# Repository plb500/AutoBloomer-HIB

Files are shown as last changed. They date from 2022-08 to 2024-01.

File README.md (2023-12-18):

# AutoBloomer Hardware Interface Board

Code and PCB design for the Hardware Interface Board, the board used by the Raspberry Pi to process sensor data and trigger relays.

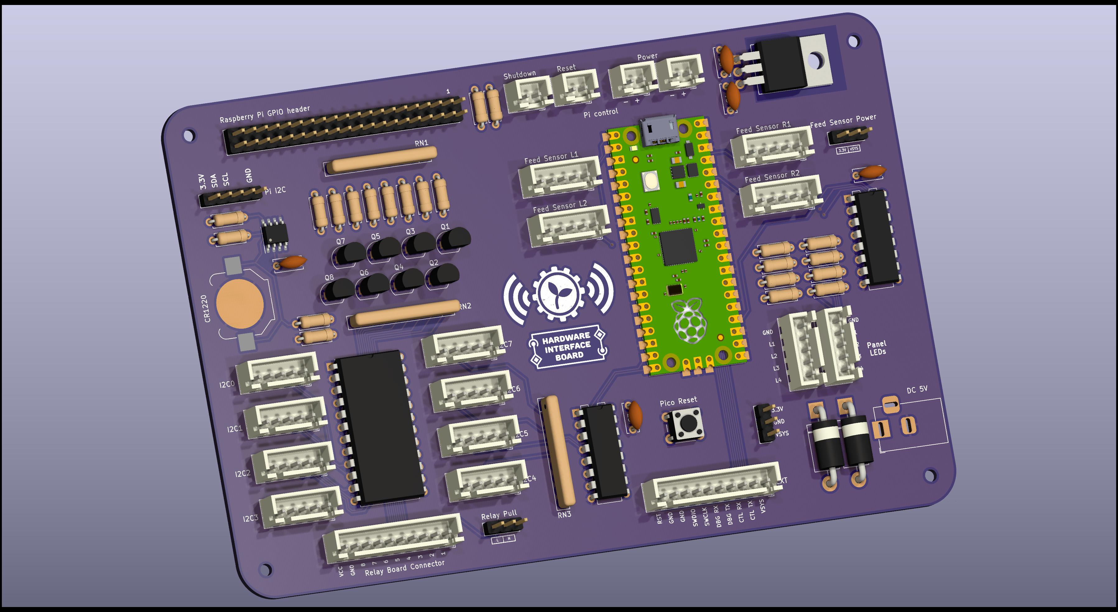
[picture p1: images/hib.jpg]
Hardware Interface Board graphic


## Features
- Raspberry Pi RTC module
- I2C expander providing up to 8 I2C device slots, along with plug detection pins for the Raspberry Pico
- Sensor multiplexing to Raspberry Pi via Raspberry Pico
- Feed level sensors
- Soil moisture sensing
- SCD30 sensing
- Ports for 8 panel/indicator LEDs
- Raspberry Pi power output ports
- Headers for external Pi shutdown/reset and Pico reset buttons
- Control circuitry and interface for properly driving common 5v relay boards (Sainsmart etc)
- Serial Wire Debug (SWD) pins exposed for debugging/programming Raspberry Pico

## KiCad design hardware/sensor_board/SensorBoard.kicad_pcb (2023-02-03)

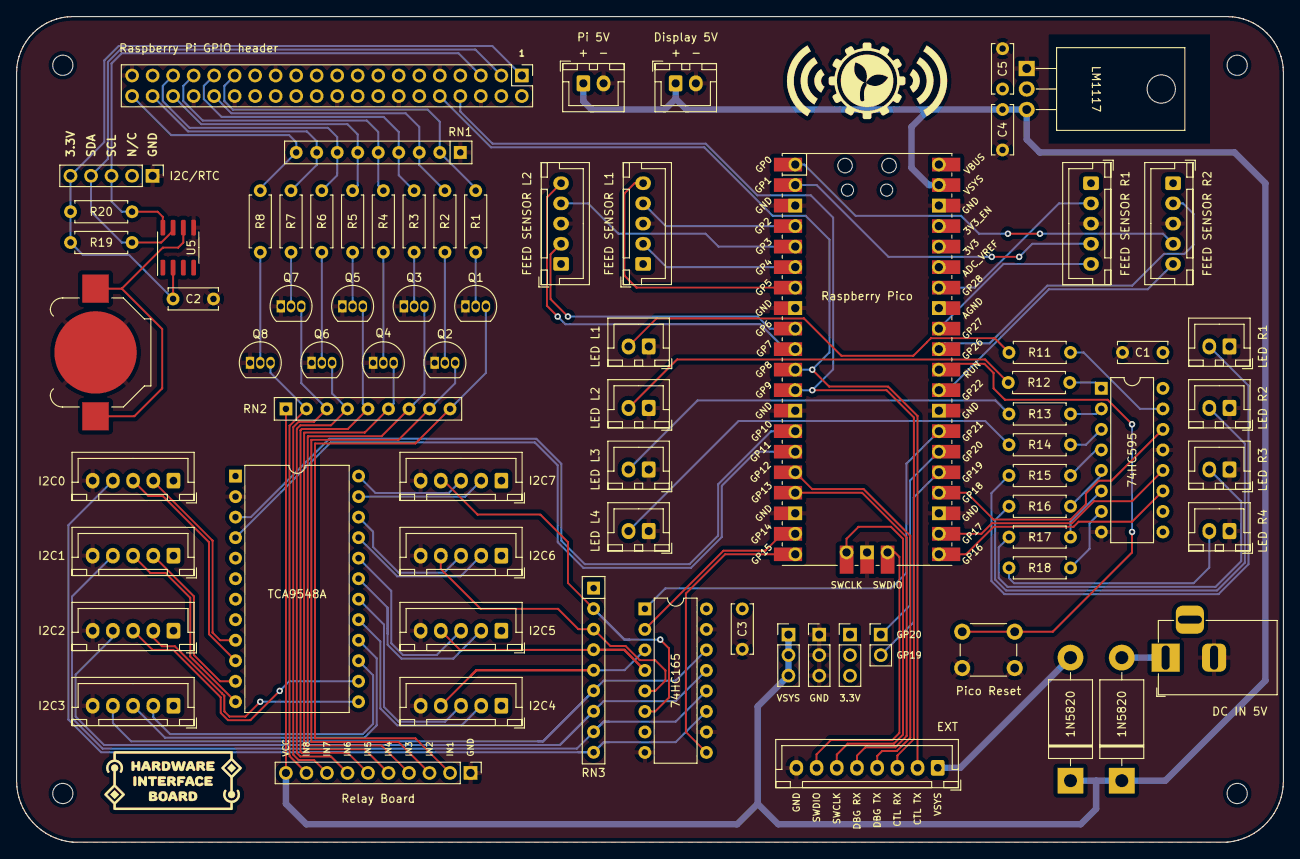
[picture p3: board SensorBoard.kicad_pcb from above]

Board: 2 copper layers, 156.9 x 102.2 mm, 79 parts (0 on the bottom side), 102 nets.

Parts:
BT1: CR1220; BatteryHolder_Keystone_3000_1x12mm
C1, C2, C3: 0.1uf; C_Disc_D6.0mm_W2.5mm_P5.00mm
C4, C5: 10uf; C_Disc_D6.0mm_W2.5mm_P5.00mm
D1, D2: 1N5820; D_DO-201AD_P15.24mm_Horizontal
H1, H2, H3, H4: MountingHole_2.5mm
J1: Relay Board; PinHeader_1x10_P2.54mm_Vertical
J2: Pi 5V; JST_XH_B2B-XH-A_1x02_P2.50mm_Vertical
J3: Display 5V; JST_XH_B2B-XH-A_1x02_P2.50mm_Vertical
J4: DC IN 5V; BarrelJack_Horizontal
J5: VSYS BUS; PinHeader_1x03_P2.54mm_Vertical
J6: FEED SENSOR L1; JST_XH_B5B-XH-A_1x05_P2.50mm_Vertical
J7: 3V3 BUS; PinHeader_1x03_P2.54mm_Vertical
J8: FEED SENSOR R1; JST_XH_B5B-XH-A_1x05_P2.50mm_Vertical
J9: FEED SENSOR L2; JST_XH_B5B-XH-A_1x05_P2.50mm_Vertical
J10: GND BUS; PinHeader_1x03_P2.54mm_Vertical
J11: FEED SENSOR R2; JST_XH_B5B-XH-A_1x05_P2.50mm_Vertical
J13: SPARE GPIO; PinHeader_1x02_P2.54mm_Vertical
J15: LED L1; JST_XH_B2B-XH-A_1x02_P2.50mm_Vertical
J16: LED L2; JST_XH_B2B-XH-A_1x02_P2.50mm_Vertical
J17: LED L3; JST_XH_B2B-XH-A_1x02_P2.50mm_Vertical
J18: LED L4; JST_XH_B2B-XH-A_1x02_P2.50mm_Vertical
J19: LED R1; JST_XH_B2B-XH-A_1x02_P2.50mm_Vertical
J20: EXT; JST_XH_B8B-XH-A_1x08_P2.50mm_Vertical
J21: LED R2; JST_XH_B2B-XH-A_1x02_P2.50mm_Vertical
J22: LED R3; JST_XH_B2B-XH-A_1x02_P2.50mm_Vertical
J23: LED R4; JST_XH_B2B-XH-A_1x02_P2.50mm_Vertical
J24: Raspberry Pi GPIO header; PinHeader_2x20_P2.54mm_Vertical
J25: RTC Header; PinHeader_1x05_P2.54mm_Vertical
J26: I2C0; JST_XH_B5B-XH-A_1x05_P2.50mm_Vertical
J27: I2C1; JST_XH_B5B-XH-A_1x05_P2.50mm_Vertical
J28: I2C2; JST_XH_B5B-XH-A_1x05_P2.50mm_Vertical
J29: I2C3; JST_XH_B5B-XH-A_1x05_P2.50mm_Vertical
J30: I2C4; JST_XH_B5B-XH-A_1x05_P2.50mm_Vertical
J31: I2C5; JST_XH_B5B-XH-A_1x05_P2.50mm_Vertical
J32: I2C6; JST_XH_B5B-XH-A_1x05_P2.50mm_Vertical
J33: I2C7; JST_XH_B5B-XH-A_1x05_P2.50mm_Vertical
Q1, Q2, Q3, Q4, Q5, Q6, Q7, Q8: PN2222A; TO-92_Inline
R1, R2, R3, R4, R5, R6, R7, R8: 2.2k; R_Axial_DIN0207_L6.3mm_D2.5mm_P7.62mm_Horizontal
R11, R12, R13: R1; R_Axial_DIN0207_L6.3mm_D2.5mm_P7.62mm_Horizontal
R14: R2; R_Axial_DIN0207_L6.3mm_D2.5mm_P7.62mm_Horizontal
R15: R3; R_Axial_DIN0207_L6.3mm_D2.5mm_P7.62mm_Horizontal
R16: R4; R_Axial_DIN0207_L6.3mm_D2.5mm_P7.62mm_Horizontal
R17: R5; R_Axial_DIN0207_L6.3mm_D2.5mm_P7.62mm_Horizontal
R18: R6; R_Axial_DIN0207_L6.3mm_D2.5mm_P7.62mm_Horizontal
R19, R20: 4.3k; R_Axial_DIN0207_L6.3mm_D2.5mm_P7.62mm_Horizontal
RN1, RN2, RN3: 10k; R_Array_SIP9
SW1: Pico Reset; SW_PUSH_6mm
U1: Raspberry Pico; RPi_Pico_SMD_TH
U2: 74HC595; DIP-16_W7.62mm
U3: TCA9548A; DIP-24_W15.24mm
U4: LM1117; TO-220-3_Horizontal_TabDown
U5: DS3231MZ; SOIC-8_3.9x4.9mm_P1.27mm
U6: 74HC165; DIP-16_W7.62mm

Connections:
+3V3: C1.1, C3.1, C5.1, J6.1, J7.1, J7.2, J7.3, J8.1, J9.1, J11.1, J26.1, J27.1, J28.1, J29.1, J30.1, J31.1, J32.1, J33.1, RN3.1 (common), U2.10 (~SRCLR), U2.16 (VCC), U3.1 (VCC), U4.2 (VO), U6.16 (VCC)
/CTL RX: J20.3, J24.8 (GPIO14/TXD), U1.12 (GPIO9)
/CTL TX: J20.2, J24.10 (GPIO15/RXD), U1.11 (GPIO8)
/DBG RX: J20.5, U1.17 (GPIO13)
/DBG TX: J20.4, U1.16 (GPIO12)
/FEED SENSOR L1 DETECT: J6.4, U1.4 (GPIO2)
/FEED SENSOR L1 RX: J6.5, U1.7 (GPIO5)
/FEED SENSOR L1 TX: J6.2, U1.6 (GPIO4)
/FEED SENSOR L2 DETECT: J9.4, U1.5 (GPIO3)
/FEED SENSOR L2 RX: J9.5, U1.10 (GPIO7)
/FEED SENSOR L2 TX: J9.2, U1.9 (GPIO6)
/FEED SENSOR R1 DETECT: J8.4, U1.2 (GPIO1)
/FEED SENSOR R1 RX: J8.5, U1.32 (GPIO27_ADC1)
/FEED SENSOR R1 TX: J8.2, U1.34 (GPIO28_ADC2)
/FEED SENSOR R2 DETECT: J11.4, U1.1 (GPIO0)
/FEED SENSOR R2 RX: J11.5, U1.29 (GPIO22)
/FEED SENSOR R2 TX: J11.2, U1.31 (GPIO26_ADC0)
/GPIO19: J13.2, U1.25 (GPIO19)
/GPIO20: J13.1, U1.26 (GPIO20)
/I2C1 SCL: U1.15 (GPIO11), U3.4 (SCL)
/I2C1 SDA: U1.14 (GPIO10), U3.3 (SDA)
/SWCLK: J20.6, U1.41 (SWCLK)
/SWDIO: J20.7, U1.43 (SWDIO)
/VSYS: D1.2 (A), J20.1
GND: BT1.2 (-), C1.2, C2.2, C3.2, C4.1, C5.2, J1.1, J2.2, J3.2, J4.2, J6.3, J8.3, J9.3, J10.1, J10.2, J10.3, J11.3, J15.1, J16.1, J17.1, J18.1, J19.1, J20.8, J21.1, J22.1, J23.1, J24.6 (GND), J24.9 (GND), J24.14 (GND), J24.20 (GND), J24.25 (GND), J24.30 (GND), J24.34 (GND), J24.39 (GND), J25.1, J26.5, J27.5, J28.5, J29.5, J30.5, J31.5, J32.5, J33.5, Q1.1 (E), Q2.1 (E), Q3.1 (E), Q4.1 (E), Q5.1 (E), Q6.1 (E), Q7.1 (E), Q8.1 (E), RN1.1 (common), SW1.1, U1.3 (GND), U1.8 (GND), U1.13 (GND), U1.18 (GND), U1.23 (GND), U1.28 (GND), U1.38 (GND), U1.42 (GND), U2.8 (GND), U2.13 (~OE), U3.2 (GND), U4.1 (GND), U5.5 (GND), U6.8 (GND), U6.10 (DS), U6.15 (~CE)
unnamed: BT1.1 (+), U5.6 (VBAT)
unnamed: C2.1, J24.1 (3V3), J25.5, R19.1, R20.1, U5.2 (VCC)
unnamed: D2.2 (A), J4.1
unnamed: J1.2, Q1.3 (C), RN2.9 (R8)
unnamed: J1.3, Q2.3 (C), RN2.8 (R7)
unnamed: J1.4, Q3.3 (C), RN2.7 (R6)
unnamed: J1.5, Q4.3 (C), RN2.6 (R5)
unnamed: J1.6, Q5.3 (C), RN2.5 (R4)
unnamed: J1.7, Q6.3 (C), RN2.4 (R3)
unnamed: J1.8, Q7.3 (C), RN2.3 (R2)
unnamed: J1.9, Q8.3 (C), RN2.2 (R1)
unnamed: J15.2, R11.2
unnamed: J16.2, R12.2
unnamed: J17.2, R13.2
unnamed: J18.2, R14.2
unnamed: J19.2, R15.2
unnamed: J21.2, R16.2
unnamed: J22.2, R17.2
unnamed: J23.2, R18.2
unnamed: J24.3 (SDA/GPIO2), J25.4, R19.2, U5.7 (SDA)
unnamed: J24.5 (SCL/GPIO3), J25.3, R20.2, U5.8 (SCL)
unnamed: J24.29 (GCLK1/GPIO5), R1.1, RN1.2 (R1)
unnamed: J24.31 (GCLK2/GPIO6), R3.1, RN1.4 (R3)
unnamed: J24.32 (PWM0/GPIO12), R2.1, RN1.3 (R2)
unnamed: J24.33 (PWM1/GPIO13), R4.1, RN1.5 (R4)
unnamed: J24.35 (GPIO19/MISO1), R6.1, RN1.7 (R6)
unnamed: J24.36 (GPIO16), R5.1, RN1.6 (R5)
unnamed: J24.38 (GPIO20/MOSI1), R7.1, RN1.8 (R7)
unnamed: J24.40 (GPIO21/SCLK1), R8.1, RN1.9 (R8)
unnamed: J26.2, U3.9 (SD0)
unnamed: J26.3, U3.10 (SC0)
unnamed: J26.4, RN3.9 (R8), U6.11 (D0)
unnamed: J27.2, U3.11 (SD1)
unnamed: J27.3, U3.12 (SC1)
unnamed: J27.4, RN3.8 (R7), U6.12 (D1)
unnamed: J28.2, U3.13 (SD2)
unnamed: J28.3, U3.14 (SC2)
unnamed: J28.4, RN3.7 (R6), U6.13 (D2)
unnamed: J29.2, U3.15 (SD3)
unnamed: J29.3, U3.16 (SC3)
unnamed: J29.4, RN3.6 (R5), U6.14 (D3)
unnamed: J30.2, U3.17 (SD4)
unnamed: J30.3, U3.18 (SC4)
unnamed: J30.4, RN3.5 (R4), U6.3 (D4)
unnamed: J31.2, U3.19 (SD5)
unnamed: J31.3, U3.20 (SC5)
unnamed: J31.4, RN3.4 (R3), U6.4 (D5)
unnamed: J32.2, U3.21 (SD6)
unnamed: J32.3, U3.22 (SC6)
unnamed: J32.4, RN3.3 (R2), U6.5 (D6)
unnamed: J33.2, U3.23 (SD7)
unnamed: J33.3, U3.24 (SC7)
unnamed: J33.4, RN3.2 (R1), U6.6 (D7)
unnamed: Q1.2 (B), R1.2
unnamed: Q2.2 (B), R2.2
unnamed: Q3.2 (B), R3.2
unnamed: Q4.2 (B), R4.2
unnamed: Q5.2 (B), R5.2
unnamed: Q6.2 (B), R6.2
unnamed: Q7.2 (B), R7.2
unnamed: Q8.2 (B), R8.2
unnamed: R11.1, U2.15 (QA)
unnamed: R12.1, U2.1 (QB)
unnamed: R13.1, U2.2 (QC)
unnamed: R14.1, U2.3 (QD)
unnamed: R15.1, U2.4 (QE)
unnamed: R16.1, U2.5 (QF)
unnamed: R17.1, U2.6 (QG)
unnamed: R18.1, U2.7 (QH)
unnamed: SW1.2, U1.30 (RUN)
unnamed: U1.19 (GPIO14), U6.2 (CP)
unnamed: U1.20 (GPIO15), U6.9 (Q7)
unnamed: U1.21 (GPIO16), U2.11 (SRCLK)
unnamed: U1.22 (GPIO17), U2.12 (RCLK)
unnamed: U1.24 (GPIO18), U2.14 (SER)
unnamed: U1.27 (GPIO21), U6.1 (~PL)
VS: C4.2, D1.1 (K), D2.1 (K), J1.10, J2.1, J3.1, J5.1, J5.2, J5.3, RN2.1 (common), U1.39 (VSYS), U4.3 (VI)

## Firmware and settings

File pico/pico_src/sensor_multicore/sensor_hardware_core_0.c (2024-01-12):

#include "hardware/sensors/sensor.h"

#include <string.h>

#include "hardware/watchdog.h"
#include "hardware/flash.h"
#include "hardware/shift_register.h"
#include "hardware/sensors/sensor_i2c_interface.h"
#include "hardware/connected_hardware_monitor.h"

#include "uart_controller/uart_sensor_controller.h"
#include "sensor_uart_control_core_1.h"
#include "sensor_multicore/sensor_multicore_utils.h"
#include "sensor_definitions.h"
#include "debug_io.h"
#include "utils.h"

#include "pico/multicore.h"
#include "pico/util/queue.h"


const uint8_t ONBOARD_LED_PIN = 25;
const bool DEBUG_SENSOR_UPDATE = false;

// Queue used for sending sensor updates from core0 to core1
queue_t sensorUpdateQueue;

// Controller interface for comms running on core 1
ControllerInterface _sensorControllerInterface = {
    .mUART = SENSOR_CONTROLLER_UART,
    .mMsgPackSensors = sensorPackets,
    .mNumMsgPackSensors = NUM_SENSORS,
    .mSensorUpdateQueue = &sensorUpdateQueue,
    .mSerialLEDPin = ONBOARD_LED_PIN
};

// Connection LED controller
ShiftRegister _ledShifter = {
    .mDataPin = LED_SR_DATA_PIN,
    .mLatchPin = LED_SR_LATCH_PIN,
    .mClockPin = LED_SR_CLOCK_PIN,
    .mType = SIPO_SHIFT_REGISTER,
    .mNumBits = 8
};

ConnectedHardwareMonitor _connectedHardwareMonitor = {
    .mConnectedHardwareRegister = {
        .mDataPin = HARDWARE_CONNECT_SR_DATA_PIN,
        .mLatchPin = HARDWARE_CONNECT_SR_LATCH_PIN,
        .mClockPin = HARDWARE_CONNECT_SR_CLOCK_PIN,
        .mType = PISO_SHIFT_REGISTER,
        .mNumBits = 16
    }
};


void update_sensor_status_indicators(ShiftRegister *shiftRegister, Sensor* sensors, uint8_t numSensors) {
    for(int i = 0; i < numSensors; ++i) {
        if(sensors[i].mSensorDefinition.mSensorConnectLEDPosition != NO_LED) {
            bool ledOn = (sensors[i].mCurrentSensorData.mSensorStatus == SENSOR_CONNECTED_VALID_DATA);
            set_shift_register_state(shiftRegister, sensors[i].mSensorDefinition.mSensorConnectLEDPosition, ledOn);
        }
    }
    write_shift_register_states(shiftRegister);
}

int main() {
    // Initialize debug serial output
    DEBUG_PRINT_INIT();

    DEBUG_PRINT("Sensor hardware core start\n");
    if (watchdog_caused_reboot()) {
        DEBUG_PRINT("Rebooted by Watchdog!\n");
    } else {
        DEBUG_PRINT("Clean boot\n");
    }

    // Enable the watchdog, requiring the watchdog to be updated every 5000ms or the chip will reboot
    // second arg is pause on debug which means the watchdog will pause when stepping through code
    watchdog_enable(5000, 1);

    // Initialize onboard LED
    gpio_init(ONBOARD_LED_PIN);
    gpio_set_dir(ONBOARD_LED_PIN, GPIO_OUT);
    gpio_put(ONBOARD_LED_PIN, false);

    DEBUG_PRINT("LEDs initialized\n");

    // Initialize the I2C interface
    init_sensor_bus(&sensorI2CInterface);

    DEBUG_PRINT("Sensor bus initialized\n");

    // Initialize status LEDs
    init_shift_register(&_ledShifter);

    // Initialize hardware connection monitor
    init_connected_hardware_monitor(&_connectedHardwareMonitor);

    // Initialize cross-core queue
    intitialize_sensor_data_queue(&sensorUpdateQueue,(NUM_SENSORS * 4));

    DEBUG_PRINT("Sensor data queue ready\n");

    // Initialise UART controller comms interface
    init_sensor_controller(&_sensorControllerInterface, SENSOR_CONTROLLER_TX_PIN, SENSOR_CONTROLLER_RX_PIN, SENSOR_CONTROLLER_BAUDRATE);

    DEBUG_PRINT("Sensor controller ready, launching controller core\n");

    // Launch secondary core (core 1)
    multicore_launch_core1(sensor_controller_core_main);

    // Activate status indicator
    gpio_put(ONBOARD_LED_PIN, true);

    // core0 execution loop
    DEBUG_PRINT("Sensor initialization complete\n");
    while(1) {
        update_connected_hardware_monitor(&_connectedHardwareMonitor);

        // Update sensor readings
        DEBUG_PRINT("Update sensors\n");
        gpio_put(ONBOARD_LED_PIN, false);
        update_sensors(sensorsList, NUM_SENSORS, DEBUG_SENSOR_UPDATE, &_connectedHardwareMonitor);
        gpio_put(ONBOARD_LED_PIN, true);

        // Update sensor LED indicators
        DEBUG_PRINT("Update LEDs\n");
        update_sensor_status_indicators(&_ledShifter, sensorsList, NUM_SENSORS);

        // Push sensor updates to core 1
        push_sensor_data_to_queue(&sensorUpdateQueue, sensorsList);

        // Pet the watchdog
        watchdog_update();

        // Chill
        sleep_ms(1);
    }
}

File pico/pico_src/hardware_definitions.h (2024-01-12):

#ifndef _HARDWARE_DEFINITIONS_H_
#define _HARDWARE_DEFINITIONS_H_

#include "hardware/i2c.h"
#include "hardware/uart.h"
#include "hardware/pio.h"
#include "pico/stdlib.h"

// Sensor status LED shift register positions
#define LED_L1      (0)
#define LED_L2      (1)
#define LED_L3      (2)
#define LED_L4      (3)
#define LED_R1      (4)
#define LED_R2      (5)
#define LED_R3      (6)
#define LED_R4      (7)

typedef enum {
    SONAR_SENSOR_L1_ACTIVE_LED      = 0,
    SONAR_SENSOR_R1_ACTIVE_LED      = 4,
    SENSOR_POD_L_ACTIVE_LED         = 1,
    SENSOR_POD_R_ACTIVE_LED         = 5,
    LED_L3_IDX                      = 2,
    LED_L4_IDX                      = 3,
    LED_R3_IDX                      = 6,
    LED_R4_IDX                      = 7,
    NO_LED                          = -1
} SensorActiveLEDPositions;

typedef enum {
    SONAR_SENSOR_L1_ACTIVE_LED_IDX      = LED_L1,
    SONAR_SENSOR_R1_ACTIVE_LED_IDX      = LED_R1,
    SENSOR_POD_L_ACTIVE_LED_IDX         = LED_L2,
    SENSOR_POD_R_ACTIVE_LED_IDX         = LED_R2,
    NO_LED_IDX                          = -1
} SensorActiveLEDIndices;

typedef enum {
    BATTERY_SENSE_ENABLE_PIN                = 0,
    BATTERY_SENSE_PIN                       = 26,

    HARDWARE_CONNECT_SR_LATCH_PIN           = 20,
    HARDWARE_CONNECT_SR_CLOCK_PIN           = 14,
    HARDWARE_CONNECT_SR_DATA_PIN            = 15,

    CONNECTION_INDICATOR_LED_SR_LATCH_PIN   = 17,
    CONNECTION_INDICATOR_LED_SR_CLOCK_PIN   = 16,
    CONNECTION_INDICATOR_LED_SR_DATA_PIN    = 18,

    SENSOR_I2C_SDA_PIN                      = 10,
    SENSOR_I2C_SCL_PIN                      = 11,
    SENSOR_I2C_MULTIPLEXER_RESET_PIN        = 1,

    SONAR_SENSOR_L1_RX_PIN                  = 4,
    SONAR_SENSOR_L1_TX_PIN                  = 5,
    SONAR_SENSOR_L2_RX_PIN                  = 6,
    SONAR_SENSOR_L2_TX_PIN                  = 7,
    SONAR_SENSOR_R1_RX_PIN                  = 27,
    SONAR_SENSOR_R1_TX_PIN                  = 28,
    SONAR_SENSOR_R2_RX_PIN                  = 21,
    SONAR_SENSOR_R2_TX_PIN                  = 22,

    SENSOR_CONTROLLER_TX_PIN                = 8,
    SENSOR_CONTROLLER_RX_PIN                = 9,

    DEBUG_UART_TX_PIN                       = 12,
    DEBUG_UART_RX_PIN                       = 13,

    LED_SR_LATCH_PIN                        = 17,
    LED_SR_CLOCK_PIN                        = 16,
    LED_SR_DATA_PIN                         = 18
} PinLabel;

typedef enum {
    FEED_SENSOR_L1_CONNECT_ID               = 0,
    FEED_SENSOR_L2_CONNECT_ID               = 1,
    FEED_SENSOR_R1_CONNECT_ID               = 3,
    FEED_SENSOR_R2_CONNECT_ID               = 2,

    I2C_DEVICE_0_CONNECT_ID                 = 8,
    I2C_DEVICE_1_CONNECT_ID                 = 9,
    I2C_DEVICE_2_CONNECT_ID                 = 10,
    I2C_DEVICE_3_CONNECT_ID                 = 11,
    I2C_DEVICE_4_CONNECT_ID                 = 12,
    I2C_DEVICE_5_CONNECT_ID                 = 13,
    I2C_DEVICE_6_CONNECT_ID                 = 14,
    I2C_DEVICE_7_CONNECT_ID                 = 15,
    
    ALWAYS_CONNECTED_CONNECT_ID             = -1,
    NEVER_CONNECTED_CONNECT_ID              = -2
} HardwareConnectID;


// I2C bus values
#define SENSOR_I2C                                      (i2c1)
static const uint SENSOR_I2C_BAUDRATE                   = (10 * 1000);

// Sonar sensor values
static const int SONAR_SENSOR_BAUDRATE                  = 9600;
#define SONAR_SENSOR_PIO                                (pio0)

// Main controller comms values (UART1)
#define SENSOR_CONTROLLER_UART                          (uart1)
static const int SENSOR_CONTROLLER_BAUDRATE             = 57600;

// Debug logging values (UART0)
#define STDIO_UART                                      (uart0)
static const int STDIO_UART_BAUDRATE                    = 57600;

// Battery sense values
static const uint8_t RTC_BATTERY_ADC_PORT               = 0;

#endif  // HARDWARE_DEFINITIONS_H

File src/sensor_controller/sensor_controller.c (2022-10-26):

#include "sensor_controller.h"

#include <math.h>
#include <stdio.h>
#include <stdlib.h>
#include <string.h>

#include "sensor_definitions.h"
#include "debug_io.h"
#include "utils.h"
#include "hardware/sensors/sensor_msgpack.h"


const uint32_t HEARTBEAT_TIMEOUT_MS = 5000;


void reset_controller_interface(ControllerInterface *controllerInterface, bool resetHeartbeat);
void send_heartbeat(ControllerInterface *controllerInterface);
void handle_incoming_byte(ControllerInterface *controllerInterface, uint8_t b);
bool convert_sensor_data(
    SensorData *sensorData,
    uint8_t numSensors,
    MsgPackSensorData *msgPackSensorData
);
void handle_sensor_controller_command(
    ControllerInterface *controllerInterface,
    Sensor **sensor,
    SensorData *sensorData,
    uint8_t numSensors
);
void handle_send_all_sensor_data_command(
    ControllerInterface *controllerInterface,
    SensorData *sensorData,
    uint8_t numSensors
);
void handle_send_sensor_data_command(
    uint8_t sensorID,
    ControllerInterface *controllerInterface,
    SensorData *sensorData,
    uint8_t numSensors
);
void write_msgpack_bytes(
    ControllerInterface *controllerInterface,
    size_t numBytes
) {
    uart_write_blocking(controllerInterface->mUART, controllerInterface->mMsgPackOutputBuffer, numBytes);
    // uart_tx_wait_blocking(controllerInterface->mUART);
}

// Resets the interface back to an initial state
void reset_controller_interface(
    ControllerInterface *controllerInterface,
    bool resetHeartbeat
) {
    controllerInterface->mCommandBufferState    = AWAITING_DATA;
    controllerInterface->mCurrentBufferPos      = 0;
    controllerInterface->mCurrentCommand        = NO_COMMAND;

    if(resetHeartbeat) {
        controllerInterface->mNextHeartbeatTime     = 0;
    }
}

// Copy data from active sensor structures into outgoing serial message object
bool convert_sensor_data(
    SensorData *sensorData,
    uint8_t numSensors,
    MsgPackSensorData *msgPackSensorData
) {
    if(!sensorData || !msgPackSensorData) {
        return false;
    }

    // Find the matching sensor data
    SensorData *foundData = 0;
    for(int i = 0; i < numSensors; ++i) {
        if(sensorData[i].mSensorID == msgPackSensorData->mSensorID) {
            foundData = &(sensorData[i]);
            break;
        }
    }

    if(!foundData) {
        return false;
    }

    // First, set the status
    msgPackSensorData->mStatus = CONNECTED_WORKING;
    if(!foundData->mIsSensorConnected) {
        msgPackSensorData->mStatus = DISCONNECTED;
    } else if(!foundData->mIsSensorReadingValid) {
        msgPackSensorData->mStatus = CONNECTED_NOT_WORKING;
    }

    // Next set the actual readings
    switch(foundData->mType) {
        case SONAR_SENSOR:
            msgPackSensorData->mSensorReadings[SONAR_SENSOR_READING_INDEX].mValue.mIntValue = foundData->mSensorReading.mSonarSensorDistance;
            break;

        case MOISTURE_SENSOR:
            msgPackSensorData->mSensorReadings[MOISTURE_SENSOR_READING_INDEX].mValue.mIntValue = foundData->mSensorReading.mMoistureSensorValue;
            break;

        case TEMP_HUMIDITY_SENSOR:
            msgPackSensorData->mSensorReadings[DHT22_TEMPERATURE_READING_INDEX].mValue.mFloatValue = foundData->mSensorReading.mTempHumidityData.mTemperatureC;
            msgPackSensorData->mSensorReadings[DHT22_HUMIDITY_READING_INDEX].mValue.mFloatValue = foundData->mSensorReading.mTempHumidityData.mRelativeHumidity;
            break;
    }

    return true;
}

// Process an incoming serial byte and create a response, if necessary
void handle_incoming_byte(ControllerInterface *controllerInterface, uint8_t b) {
    if(b == COMMAND_START_BYTE) {
        reset_controller_interface(controllerInterface, false);
        return;
    }
    
    controllerInterface->mCommandBuffer[controllerInterface->mCurrentBufferPos++] = b;

    if(controllerInterface->mCurrentBufferPos != COMMAND_LENGTH) {
        controllerInterface->mCommandBufferState = PROCESSING_COMMAND_DATA;
        return;
    }
    
    // We have a complete command, reset the buffer position and process the command
    controllerInterface->mCurrentBufferPos = 0;

    // Validate checksum
    uint16_t checksum = 0;
    for (int i = 0; i < COMMAND_LENGTH - 1; ++i) {
        checksum += controllerInterface->mCommandBuffer[i];
    }

    // Checksum was invalid, set invalid state and return
    if((checksum & 0xFF) != controllerInterface->mCommandBuffer[COMMAND_LENGTH - 1]) {
        controllerInterface->mCommandBufferState = HAS_INVALID_COMMAND_DATA;
        return;
    }

    // Complete, valid command. Process
    controllerInterface->mCommandBufferState = HAS_COMPLETE_COMMAND;
    controllerInterface->mCurrentCommand = (SensorCommandIdentifier) controllerInterface->mCommandBuffer[0];
}

void handle_calibrate_sensor_command(Sensor** sensors, int numSensors, uint8_t *calibrationValueBytes) {
    MsgPackCalibrationValue calibration = unpack_calibration_value(calibrationValueBytes, ARGUMENT_LENGTH);

    Sensor *calibrationSensor = 0;
    for(int i = 0; i < numSensors; ++i) {
        if(sensors[i]->mSensorID == calibration.mSensorID) {
            calibrationSensor = sensors[i];
            break;
        }
    }

    if(!calibrationSensor) {
        return;
    }

    switch(calibrationSensor->mSensorType) {
        // case LOAD_SENSOR:
        //     DEBUG_PRINT("Calibrating load sensor %d with value %f\n", calibration.mSensorID, calibration.mCalibrationValue.mFloatValue);
        //     calibrate_hx711_sensor_to_value(&calibrationSensor->mSensor.mHX711, calibration.mCalibrationValue.mFloatValue);
        //     break;
        case TEMP_HUMIDITY_SENSOR:
        case MOISTURE_SENSOR:
        default:
            break;
    }
}

// Transmit a heartbeat pulse packet
void send_heartbeat(ControllerInterface *controllerInterface) {
    PackResponse response;

    // Pack and send the header data
    response = pack_heartbeat_packet(controllerInterface->mMsgPackOutputBuffer, MPACK_OUT_BUFFER_SIZE);
    if(!response.mErrorCode) {
        write_msgpack_bytes(controllerInterface, response.mBytesUsed);
    }

    // Pack and send terminator packet
    response = pack_terminator_packet(HEARTBEAT_PACKET, controllerInterface->mMsgPackOutputBuffer, MPACK_OUT_BUFFER_SIZE);
    if(!response.mErrorCode) {
        write_msgpack_bytes(controllerInterface, response.mBytesUsed);
    }
}
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

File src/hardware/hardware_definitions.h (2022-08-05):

#ifndef HARDWARE_DEFINITIONS_H
#define HARDWARE_DEFINITIONS_H

#include "hardware/i2c.h"
#include "hardware/uart.h"
#include "pico/stdlib.h"

// Time utility
#define MILLIS() (to_ms_since_boot(get_absolute_time()))

// Sensor status LED pins
typedef enum {
    LOAD_SENSOR_L_ACTIVE_LED        = 21,
    LOAD_SENSOR_R_ACTIVE_LED        = 16,
    TEMP_SENSOR_L_ACTIVE_LED        = 19,
    TEMP_SENSOR_R_ACTIVE_LED        = 18,
    MOISTURE_SENSOR_L_ACTIVE_LED    = 20,
    MOISTURE_SENSOR_R_ACTIVE_LED    = 17
} SensorActiveLEDPins;

// Sensor connection detection pins
typedef enum {
    LOAD_SENSOR_L_JACK_DETECT_PIN       = 1,
    LOAD_SENSOR_R_JACK_DETECT_PIN       = 4,
    TEMP_SENSOR_L_JACK_DETECT_PIN       = 2,
    TEMP_SENSOR_R_JACK_DETECT_PIN       = 3,
    MOISTURE_SENSOR_L_JACK_DETECT_PIN   = 0,
    MOISTURE_SENSOR_R_JACK_DETECT_PIN   = 5
} SensorActiveJackDetectPins;


// Soil moisture sensor pins (I2C-1)
#define SENSOR_I2C                                      (i2c1)
static const uint SENSOR_I2C_BAUDRATE                   = (100 * 1000);
static const uint8_t MOISTURE_I2C_SDA                   = 6;
static const uint8_t MOISTURE_I2C_SCL                   = 7;

// Load sensor data pins (outputs)
static const uint8_t LOAD_SENSOR_SDA_L                  = 28;
static const uint8_t LOAD_SENSOR_SCL_L                  = 27;
static const uint8_t LOAD_SENSOR_SDA_R                  = 26;
static const uint8_t LOAD_SENSOR_SCL_R                  = 22;

// Load sensor control pins (input)
static const uint8_t LOAD_SENSOR_TARE_L                 = 10;
static const uint8_t LOAD_SENSOR_TARE_R                 = 11;

// Temperature sensor pins (input/output)
static const uint8_t TEMP_SENSOR_L_CTL                  = 14;
static const uint8_t TEMP_SENSOR_R_CTL                  = 15;

// Main controller comms pins and values (UART0)
#define SENSOR_CONTROLLER_UART                          (uart1)
static const uint8_t SENSOR_CONTROLLER_RX               = 13;
static const uint8_t SENSOR_CONTROLLER_TX               = 12;
static const int SENSOR_CONTROLLER_BAUDRATE             = 19200;

// Debug/Serial output macro block
#define DEBUG_PRINT_ON                                  1       // Set to 0 to disable all stdio UART logging

#if DEBUG_PRINT_ON
#   define DEBUG_PRINT_BUF_SIZE                         (128)
static char DEBUG_PRINT_BUF[DEBUG_PRINT_BUF_SIZE];

// Debug logging pins and values (UART1)
#   define STDIO_UART                                   (uart0)
static const uint8_t UART_RX                            = 8;
static const uint8_t UART_TX                            = 9;
static const int STDIO_UART_BAUDRATE                    = 19200;


// Initialize the debug logging system
#   define DEBUG_PRINT_INIT()                              { \
        gpio_set_function(UART_TX, GPIO_FUNC_UART); \
        gpio_set_function(UART_RX, GPIO_FUNC_UART); \
        uart_init(STDIO_UART, STDIO_UART_BAUDRATE); \
        uart_set_format (STDIO_UART, 8, 1, UART_PARITY_NONE); \
        uart_set_hw_flow(STDIO_UART, false, false); \
    }

// Print the supplied sformatted string to debug out UART
#   define DEBUG_PRINT(format, ...)                        { \
        snprintf(DEBUG_PRINT_BUF, DEBUG_PRINT_BUF_SIZE, format __VA_OPT__(,) __VA_ARGS__); \
        uart_puts(STDIO_UART, DEBUG_PRINT_BUF); \
    }

// Shut down the debug logging UART
#   define DEBUG_PRINT_DEINIT()                            { \
    (uart_deinit(STDIO_UART); \
    }
#else
// No-op all debug logging functions
#   define DEBUG_PRINT_INIT()                              {}
#   define DEBUG_PRINT(format, ...)                        {}
#   define DEBUG_PRINT_DEINIT()                            {}
#endif

#endif  // HARDWARE_DEFINITIONS_H

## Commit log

2022-07-15 Made a sensor simulator just to make it a bit easier to write the serial processing on the main controller
2022-07-17 Think I have a pretty workable interface for sending back generic sensor details/data. Tested inside of a python sample app in Controller repo
2022-07-17 Adding a startup signal to the simulator. Probably won't be necessary on the real device but it's required on the Arduino serial
    [sensor_simulator.ino]
2022-07-24 Overhauling serial responses. No longer splitting up descriptions from data. There is no point to doing this currently
    [sensor_simulator.ino]
2022-08-05 Rewrote Pico controller to completely use msgpack for serial comms and fixed as many bugs as I could find. Basic functionality looks to be working. Haven't test with full suite of sensors yet.
    [hardware_definitions.h, sensor.c, sensor.h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]
2022-08-05 Swap L and R hardware definitions to match box orientation. Some more code housekeeping
    [hardware_definitions.h]
2022-08-05 Fixed some naming and added a send ready command and response
    [hardware_definitions.h, sensor_controller.c]
2022-08-07 Making load sensor calibratable. Plus making it a bit easier to calibrate other sensors should we need to
2022-08-18 PCB for sensor controller, some other sensor controller hardware files (CNC stuff etc)
    [SensorBoard.kicad_pcb, SensorBoard.kicad_sch]
2022-09-13 Massive sensor controller update. Removed weight sensor for feed levels, replaced with sonar. Lots of other code improvements, including read/update loop speed adn configuration changes to match PCB 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
    [hardware_definitions.h, sensor.c, sensor.h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]
2022-09-13 PCB v2.0. Using sonars instead of load cells, which frees up the tare buttons. Also using a shift register for LEDs instead of direct GPIO control which frees up three more pins.
    [SensorBoard.kicad_pcb, SensorBoard.kicad_sch]
2022-09-13 Some CNC files for load cell mounts (defunct) and sonar sensor frames (funct)
2022-09-13 Fixed error in shift register wiring
    [SensorBoard.kicad_pcb, SensorBoard.kicad_sch]
2022-09-13 Forgot to actually copy across sonar values into msgpack
2022-09-13 Setting export directory
    [SensorBoard.kicad_pcb]
2022-10-26 Fixing up hardware definitions to match new board layout. Fixing some minor issues with hotplugging
    [hardware_definitions.h, sensor.h, sensor_controller.c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]
2022-12-12 Updating some schematics
2022-12-12 Matching pins in code up to actual board layout
2022-12-12 Tidying up PCB a little bit
    [SensorBoard.kicad_pcb]
2022-12-12 Pushing up some old sim codem which may or may not work any more
    [sensor_simulator.ino]
2023-01-31 Brand new sensor board, includes I2C expander, RTC and relay board connections
    [SensorBoard.kicad_pcb, SensorBoard.kicad_sch]
2023-02-02 New version without DHT22. Full exposed I2C expander
    [SensorBoard.kicad_pcb, SensorBoard.kicad_sch]
2023-02-03 Completely revamped board. Will fully use the I2C expander now to have one "sensor pod" per grow system containing an SCD30 and a soil sensor. This allows for 8 sensor pods. Will reuse the I2C interf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
    [SensorBoard.kicad_pcb, SensorBoard.kicad_sch]
2023-02-03 Beautifying board
    [SensorBoard.kicad_sch]
2023-02-04 Final 3.0 tweakage. Gerbers sent to OSHPark
    [SensorBoard.kicad_sch]
2023-10-14 Merge multicore into main branch (#1)
    * Attempting to switch back to a multicore implementation. Changing data structure to better support transferring live sensor data between cores
    * Refactoring msgpack wrappers to support multicore
    * Refactoring completed. Need to test on actual hardware now
    * Some final tidy up and housekeeping plus fixing bug which was causing delayed startup (we weren't sending the controller ready packet properly(
    * Butchering my way through the code, integrating the new sensor pod.
    * Think everything is wrangled together now. Tests show comms to sensors working. Multicore serial comms looks to be a lot faster. Still some inefficiencies in how we are st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
    [hardware_definitions.h, sensor.c, sensor.h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]
2023-10-14 Modifying HIB to include relay pull jumper (for defaulting relay inputs to HIGH or LOW on startup)
    [SensorBoard.kicad_sch]
2023-10-19 Board revisions 3.1 - added mutiple external switch connectors, clock battery sensing path to pico, jumpers to control feed sensor outputs and relay pulls
    [SensorBoard.kicad_sch]
2023-10-21 Repo cleanup/housekeeping
    [HardwareInterfaceBoard.kicad_sch]
2023-11-09 Adding rudimentary bettery sensor. Matching hardware pin definitions to new board revision
2023-12-14 First crack at fixing the sensor pod stalling. Adding extra logging and some depth to I2C functions
    [hardware_definitions.h, sensor.c, sensor_hardware_core_0.c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]
2023-12-14 Adding in sensor pod watchdog. Will attempt to reset hardware if it doesn't respond
    [sensor_pod.c]
2023-12-16 Can reset watchdog timer if we only have one reading
    [sensor_pod.c]
2023-12-26 Fixing up a bug with not resetting sensor pod properly. Adjusting hardware definitions to match actual hardware
    [sensor_definitions.c, sensor_pod.c]
2023-12-26 Trying to free up Pico pins by using another shift register
    [HardwareInterfaceBoard.kicad_sch]
2024-01-01 Board arrangement/tidying
    [HardwareInterfaceBoard.kicad_sch]
2024-01-02 (Hopefully) adding in the ability to reset the multiplexer if it gets stuck adn starts timing out
    [hardware_definitions.h, sensor_definitions.c, sensor_hardware_core_0.c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]
2024-01-03 New board revision - main change is a better RTC battery sensing circuit. Also general board tidying/improvements, cleaned up the graphics folder, updated some graphics etc
    [HardwareInterfaceBoard.kicad_sch]
2024-01-04 Added in some badly set resistor values
    [HardwareInterfaceBoard.kicad_sch]
2024-01-10 Allowing I2C bus to be reset independently from I2C sensors and supporting chained shift registers
    [hardware_definitions.h, sensor.c, sensor_definitions.c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]
2024-01-10 Tidying up some labeling on PCB
2024-01-12 Part 1 - switching all hardware connect detect to the shift register hardware solution
2024-01-12 Adding new, better battery sensing code (MOSFET-based circuit)

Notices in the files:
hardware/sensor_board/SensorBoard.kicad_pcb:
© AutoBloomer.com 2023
